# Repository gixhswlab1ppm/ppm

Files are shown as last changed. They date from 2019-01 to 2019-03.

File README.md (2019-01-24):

# Summary
Table tennis can be an expensive sport to learn, with the quality and costs of coaches being hard to determine. Our project aims to make it easier and cheaper to learn table tennis. Our design objective is to create a hardware device that can be connected to a table tennis paddle and be used for various training purposes. Our first objective is to ensure that we can collect useful data. One way in which we will test that is by using unsupervised learning to help users mimic each other, like you might find with a coach and trainee. Our ending objective is to classify different gestures and moves, then to use that data for more complex learning to help users train independently of a coach through real time feedback and post-training analysis through a web interface.
 
# Statement of Problem
Table tennis (commonly referred to as “ping pong”) is an Olympic sport, and a difficult one to learn on a professional level; some countries only have a handful of professional players, and they tend to have played for a long time, taking lessons for 5-15 years (source). Lessons from professional coaches can cost anywhere from $20-100, and there are a wide number of attacking and defensive strokes that players must learn, as well as transitions from each stroke to the other (source). Approximately 19 million Americans play table tennis (source), but only 9000 Americans are registered in the national semi-professional organization (source). This means that almost all table tennis players in the United States have not had professional training.

# Technical Documentation
It's using Python and Arduino/Raspberry Pi. It does ML via sklearn, and data viz via matplotlib.

# Usage Instructions
Run the file

# Notes:
Manually measured swing-period:
cutuy_swing_walk 2s

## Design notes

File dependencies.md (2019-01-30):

# rpi-dep
- pyserial (import serial)
- 
# ard-dep
- MPU6050_tockn (Arduino IDE; source code modified)
- 
# viz-dep
- 

# dev-dep

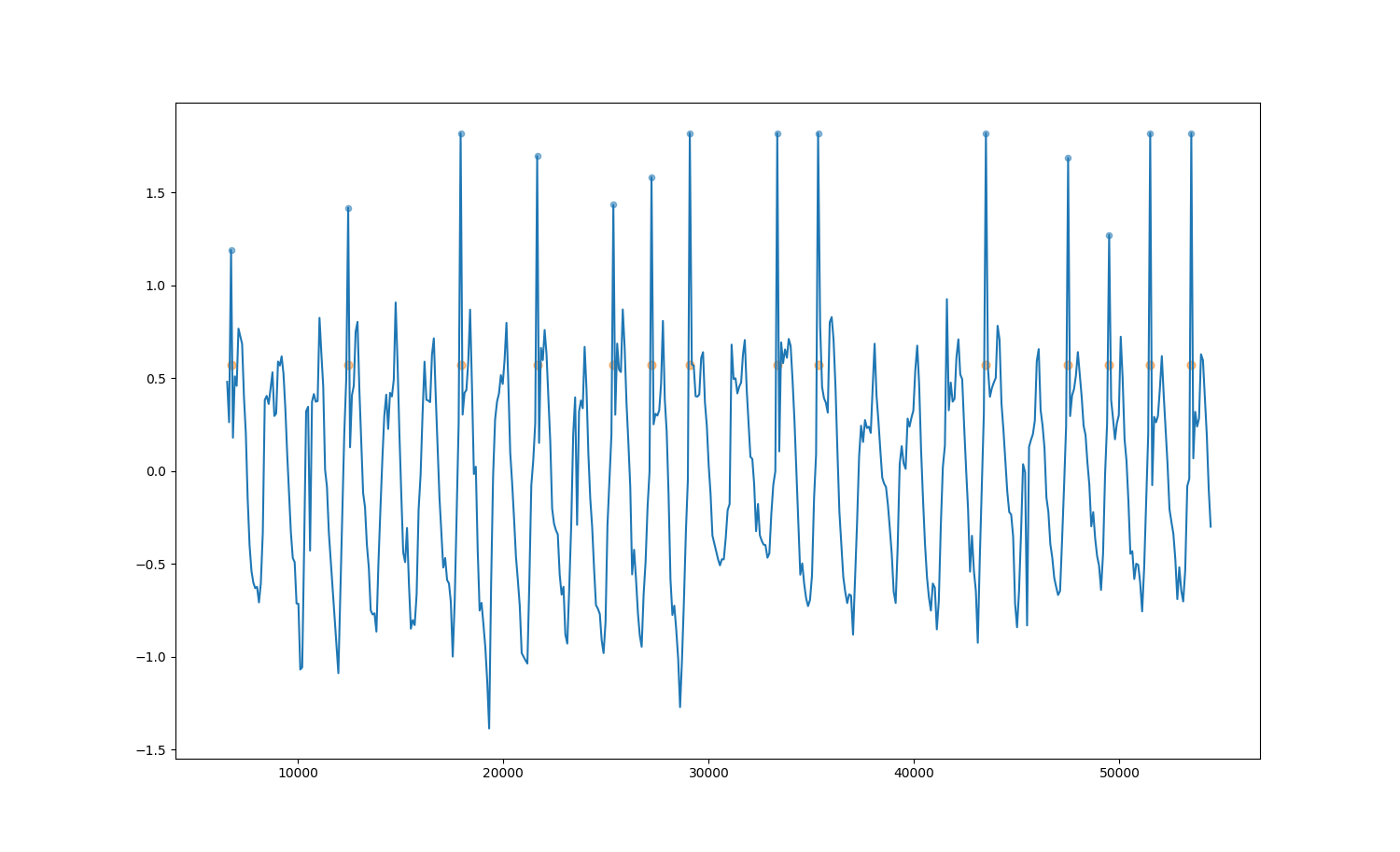
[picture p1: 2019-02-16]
insights/Figure_10.png

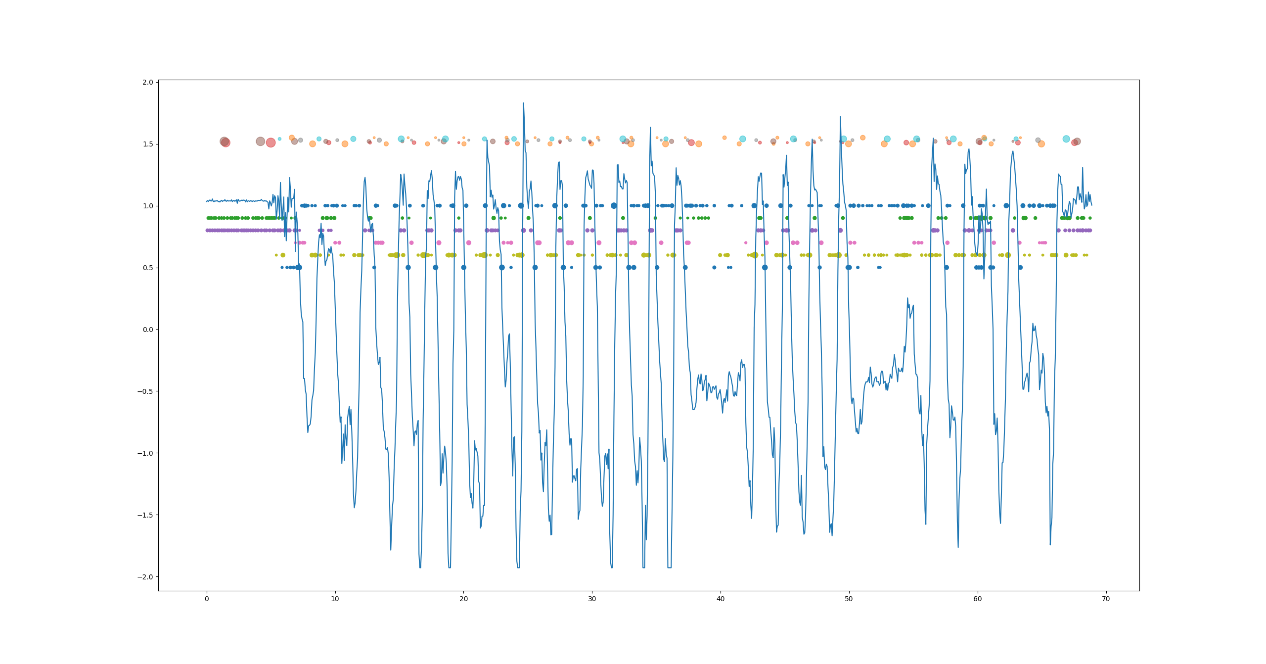
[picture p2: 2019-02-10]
insights/Figure_2.png

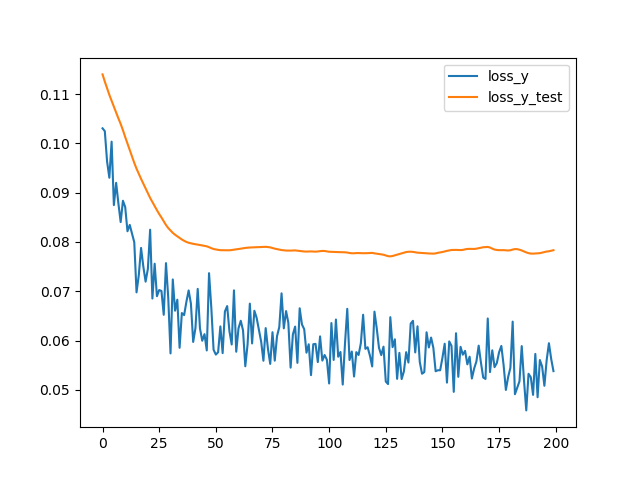
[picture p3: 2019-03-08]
insights/Figure_37.png

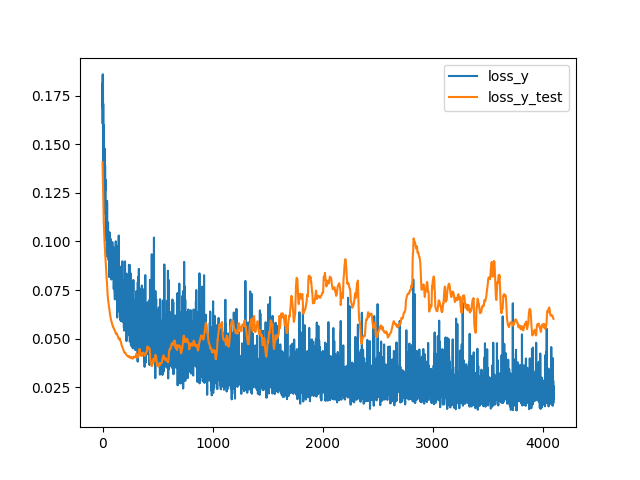
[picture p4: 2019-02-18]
insights/Figure_30.png

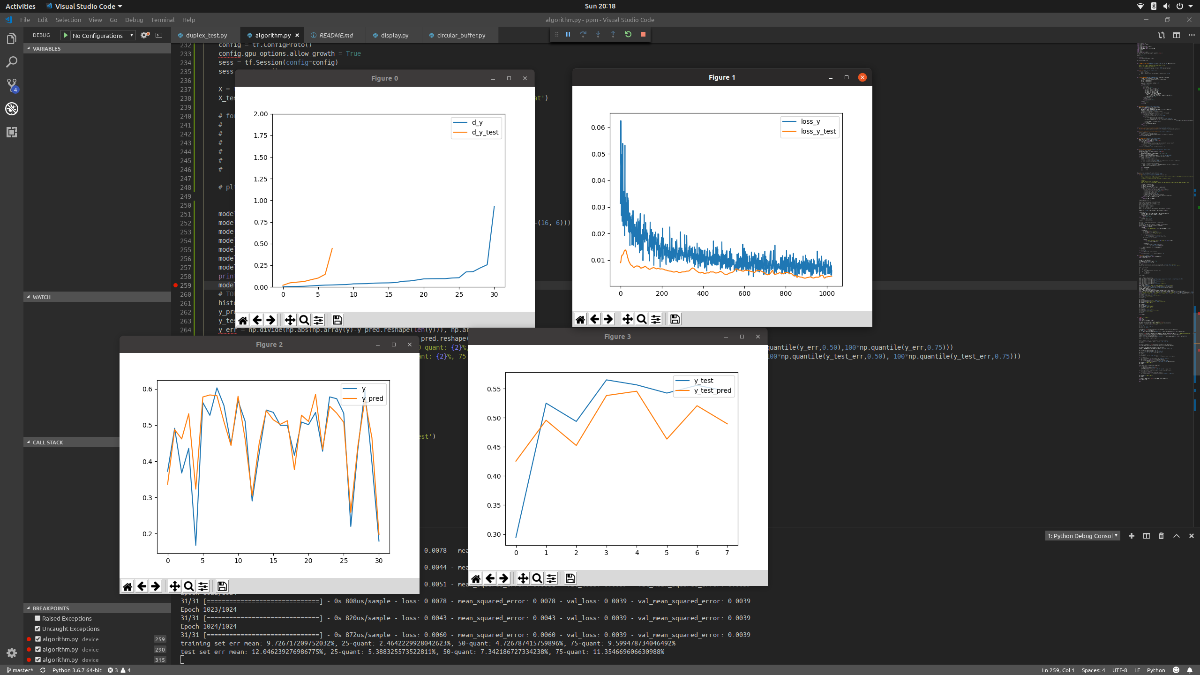
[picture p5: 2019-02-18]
insights/Screenshot from 2019-02-17 20-18-54.png

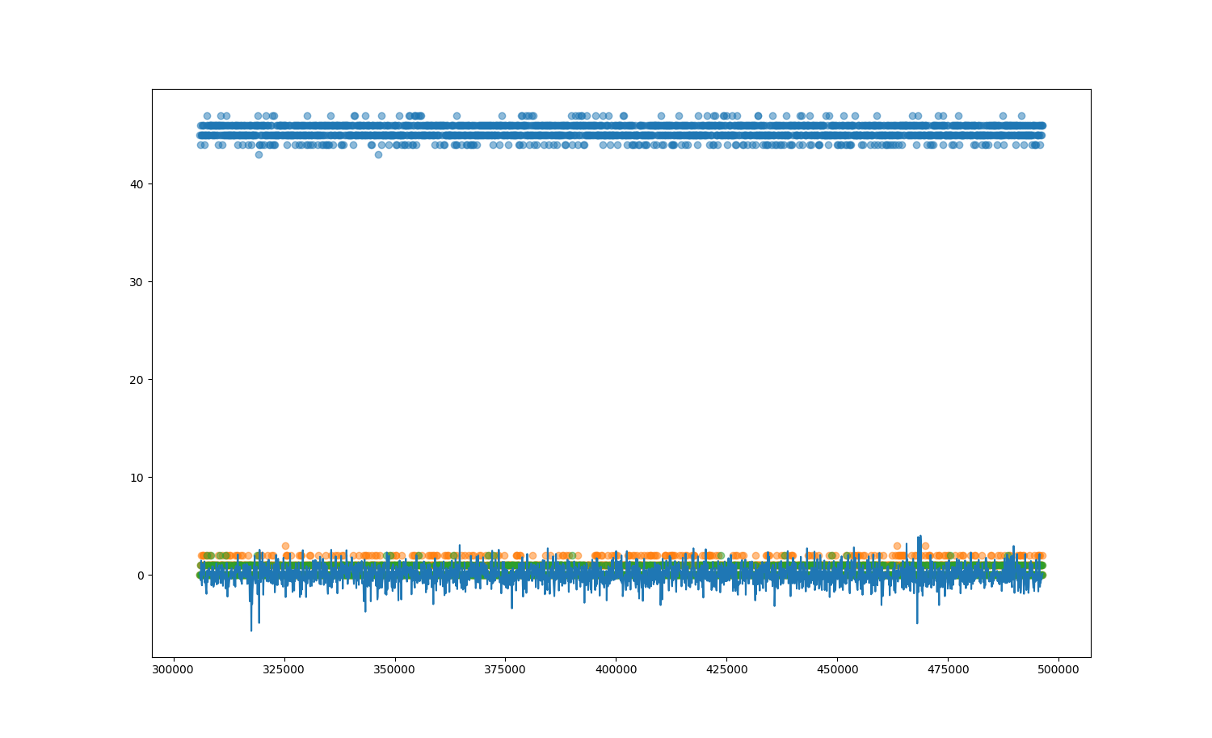
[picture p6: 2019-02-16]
insights/Figure_8.png

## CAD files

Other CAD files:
Paddle RC1.0 (Jason).f3d
Paddle v2 v16.f3d
Paddle v8.f3d

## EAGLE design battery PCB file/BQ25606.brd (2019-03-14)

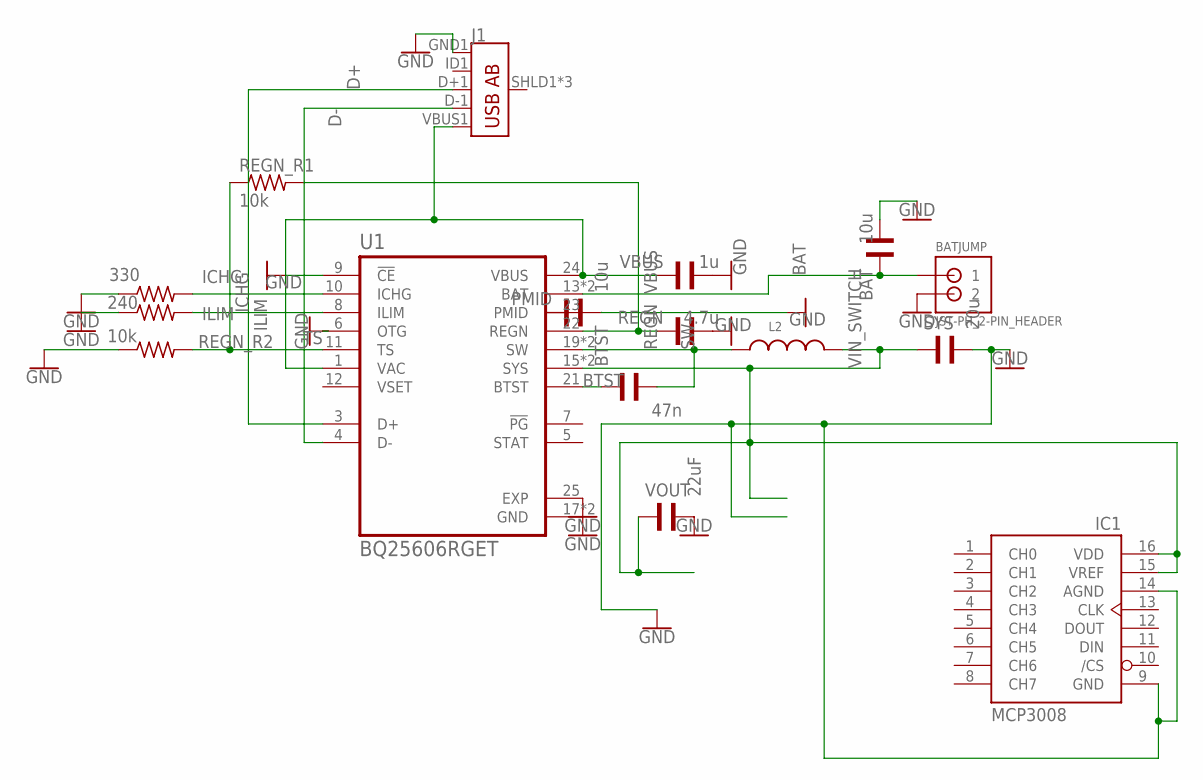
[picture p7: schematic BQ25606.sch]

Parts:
BAT: 10u; WCAP-CSMH_0805_REFLOW; MPN GRM21BR61E106KA73L
BATJUMP: JST-PH_2-PIN_HEADER; JST_B2B-PH_HEADER
BTST: 47n; WCAP-CSGP_0805_WAVE; MPN MC0805B473K500CT
IC1: MCP3008; DIL16
ICHG: 330; M0805; MPN RR1220P-331-D
ILIM: 240; M0805
J1: USB_AB_SMT; USB-AB-MICRO-SMD
L2: WE-PMI_0805_74479775215; WE-PMI_0805
PMID: 10u; WCAP-CSMH_0805_REFLOW; MPN C2012X5R1A226M125AB
REGN: 4.7u; WCAP-CSGP_0805_WAVE; MPN C2012X5R1H475K125AB
REGN_R1, REGN_R2: 10k; M0805; MPN ERJ-6ENF1002V
SYS: 20u; WCAP-CSMH_0805_REFLOW; MPN CC0402KRX5R6BB105
U1: BQ25606RGET; QFN50P400X400X100-25N270X270; MPN BQ25606RGET .
VBUS: 1u; WCAP-CSMH_0805_REFLOW; MPN MCTT21X105K160CT
VOUT: 22uF; WCAP-CSMH_0805_REFLOW; MPN CC0402KRX5R6BB105

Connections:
BAT: BAT.2, BATJUMP.P1 (1), U1.13 (BAT), U1.14 (BAT)
BTST: BTST.2, U1.21 (BTST)
D+: J1.D+1 (D+), U1.3 (D+)
D-: J1.D-1 (D-), U1.4 (D-)
GND: BAT.1, BATJUMP.P2 (2), IC1.9 (GND), IC1.14 (AGND), ICHG.1, ILIM.1, J1.GND1 (GND), PMID.1, REGN.1, REGN_R2.1, SYS.1, U1.6 (OTG), U1.9 (!CE), U1.17 (GND), U1.18 (GND), U1.25 (EXP), VBUS.1, VOUT.1
ICHG: ICHG.2, U1.10 (ICHG)
ILIM: ILIM.2, U1.8 (ILIM)
PMID: U1.23 (PMID)
REGN: REGN.2, REGN_R1.2, U1.22 (REGN)
SW: BTST.1, L2.1, U1.19 (SW), U1.20 (SW)
TS: REGN_R1.1, REGN_R2.2, U1.11 (TS)
VBUS: J1.VBUS1 (VBUS), U1.1 (VAC), U1.24 (VBUS), VBUS.2
VIN_SWITCH: IC1.15 (VREF), IC1.16 (VDD), L2.2, SYS.2, U1.15 (SYS), U1.16 (SYS), VOUT.2

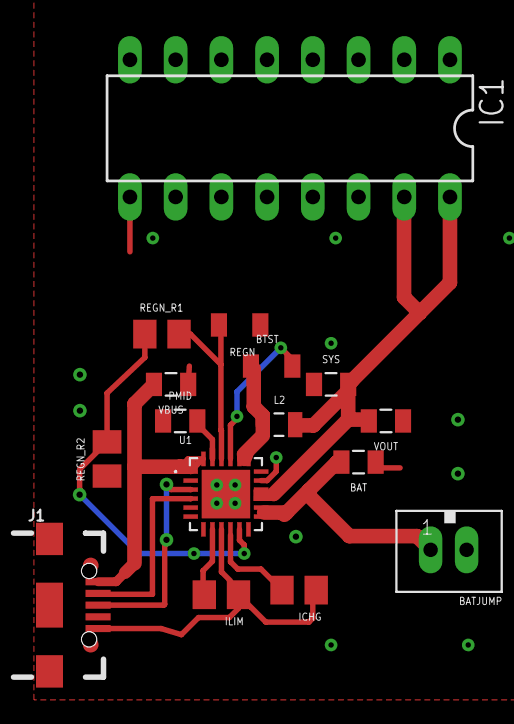
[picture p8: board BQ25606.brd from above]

Board: 2 copper layers, 16 parts (0 on the bottom side), 12 nets.

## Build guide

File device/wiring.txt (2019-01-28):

RPi <-> Arduino Uno <-> 3 x Contact Mic (A0-A2) + 1 x IMU (A4-A5)

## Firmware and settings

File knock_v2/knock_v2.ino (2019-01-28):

/*
  Knock Sensor

  This sketch reads a piezo element to detect a knocking sound.
  It reads an analog pin and compares the result to a set threshold.
  If the result is greater than the threshold, it writes "knock" to the serial
  port, and toggles the LED on pin 13.

  The circuit:
  - positive connection of the piezo attached to analog in 0
  - negative connection of the piezo attached to ground
  - 1 megohm resistor attached from analog in 0 to ground

  created 25 Mar 2007
  by David Cuartielles <http://www.0j0.org>
  modified 30 Aug 2011
  by Tom Igoe

  This example code is in the public domain.

  http://www.arduino.cc/en/Tutorial/Knock
*/


// these constants won't change:
const int ledPin = 13;      // LED connected to digital pin 13
const int knockSensor_1 = A0; // the piezo is connected to analog pin 0
const int knockSensor_2 = A1; // the piezo is connected to analog pin 0
const int knockSensor_3 = A2; // the piezo is connected to analog pin 0
const int threshold = 10;  // threshold value to decide when the detected sound is a knock or not


// these variables will change:
int sensorReading_1 = 0;      // variable to store the value read from the sensor pin
int sensorReading_2 = 0;      // variable to store the value read from the sensor pin
int sensorReading_3 = 0;      // variable to store the value read from the sensor pin
int ledState = LOW;         // variable used to store the last LED status, to toggle the light

void setup() {
  pinMode(ledPin, OUTPUT); // declare the ledPin as as OUTPUT
  Serial.begin(9600);       // use the serial port
}

void loop() {
  // read the sensor and store it in the variable sensorReading:
  sensorReading_1 = analogRead(knockSensor_1);
  if (sensorReading_1 > threshold) {
    Serial.println("sensor 1:");
    Serial.println(sensorReading_1);
  }
  sensorReading_2 = analogRead(knockSensor_2);
  if (sensorReading_2 > threshold) {
    Serial.println("sensor 2:");
    Serial.println(sensorReading_2);
  }
  sensorReading_3 = analogRead(knockSensor_3);
  if (sensorReading_3 > threshold) {
    Serial.println("sensor 3:");
    Serial.println(sensorReading_3);
  }
  // if the sensor reading is greater than the threshold:
  if (sensorReading_1 + sensorReading_2 + sensorReading_3 >= (threshold * 3)) {
    // toggle the status of the ledPin:
    ledState = !ledState;
    // update the LED pin itself:
    digitalWrite(ledPin, ledState);
    // send the string "Knock!" back to the computer, followed by newline
    Serial.println("Knock!");
    Serial.println("Estimate: ");
    if (sensorReading_3 < sensorReading_1) {
      if (sensorReading_3 < sensorReading_2) {
        Serial.println("Ball in between 1 and 2");
      }
    }
    if (sensorReading_2 < sensorReading_1) {
      if (sensorReading_2 < sensorReading_3) {
        Serial.println("Ball in between 1 and 3");
      }
    }
    if (sensorReading_1 < sensorReading_3) {
      if (sensorReading_1 < sensorReading_2) {
        Serial.println("Ball in between 3 and 2");
      }
    }
  }
  delay(100);  // delay to avoid overloading the serial port buffer
}

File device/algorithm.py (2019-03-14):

import numpy as np
import math
from collections import Counter
from scipy import stats
from scipy.signal import argrelextrema
import ujson
import os
from scipy import stats
dir_path = os.path.dirname(os.path.realpath(__file__))

visualize = False
debug = False

hit_th = 200
hit_cluster_size = 1000
ts_col = 0
mpu_cols = [1, 2, 3, 4, 5, 6]
hit_cols = [7, 8, 9]

if visualize == True:
    import matplotlib.pyplot as plt

#  stateless algorithms


# center must be (0,0)
def triangulate_centroid(readings, circles=[[-1/2, -math.sqrt(3)/6], [0, 1./math.sqrt(3)], [1/2, -math.sqrt(3)/6]]):
	"""
	Given a 1x3 array of readings, and 3x2 array of circles
	Returns the weighted centroid (1x2)
	"""
	return np.divide(np.dot(readings, circles), .00001+np.sum(readings))


def shift_mean(data, ts_col, feature_cols):
    return np.hstack([
        data[:, [ts_col]],
        data[:, feature_cols] - np.mean(data[:, feature_cols], axis=0)
    ])


def clustering_dedup(maximas, seg_span=1500):  # maximas: timestamps
        # merge within window until no change
        # 2-level clustering (dedup then detect, respectively)
        idx_min = maximas.min()
        idx_max = maximas.max()

        segs = np.array(maximas).reshape(-1, 1)
        if debug == True:
            print(len(segs))
        while True:
            curr_seg_idx = 0
            epoch_updated = False
            while curr_seg_idx < len(segs) - 1:
                curr_seg = segs[curr_seg_idx]
                next_seg = segs[curr_seg_idx+1]
                curr_mean = np.mean(curr_seg)
                next_mean = np.mean(next_seg)
                if next_mean - curr_mean < seg_span:
                    segs = [*segs[:curr_seg_idx],
                            [*curr_seg, *next_seg], *segs[curr_seg_idx+2:]]
                    epoch_updated = True
                curr_seg_idx += 1
            if debug == True:
                print(len(segs))
            if epoch_updated == False:
                break
        if debug == True:
            print("!!!")
        return segs


def swing_count_svc(data, ts_col, feature_cols, pre_thresholds=None): # =[.3, .2, .34, 50, 30, 35]
    # data = shift_mean(data, ts_col, feature_cols)
    cluster_ts_per_feature = []
    curr_thresholds = np.ndarray((len(feature_cols)))
    for i in range(0, len(feature_cols)):
        maxima_idx = np.array(argrelextrema(data[:, i+1], np.greater))[0]
        curr_thresholds[i] = data[:, i+1].std()*0.6
        if pre_thresholds is None:
            threshold = curr_thresholds[i]
        else:
            threshold = pre_thresholds[i]

        maxima_idx_filtered = [
            m_i for m_i in maxima_idx if data[m_i, i+1] > threshold]
        if len(maxima_idx_filtered) > 0:
            cluster_ts = clustering_dedup(
                data[maxima_idx_filtered, 0], seg_span=1500)
            if visualize:
                plt.scatter(data[maxima_idx_filtered, 0],
                            data[maxima_idx_filtered, i+1], s=20, alpha=.5)
                plt.scatter([np.mean(tsd) for tsd in cluster_ts], pre_thresholds[i] * np.ones(len(cluster_ts)), s=40, alpha=.5)
                plt.plot(data[:, 0], data[:, i+1])
                plt.show()
            cluster_ts_per_feature.append(cluster_ts)
        else:
            cluster_ts_per_feature.append([])
    return cluster_ts_per_feature, curr_thresholds


def get_swing_count_from_ts_clusters_by_feature(ts_clusters_by_feature):
    return int(np.round(np.median([len(clusters) for clusters in ts_clusters_by_feature])))


def get_swing_centers_from_ts_cluster_by_feature(ts_clusters_by_feature):
    centers_by_feature = []
    for clusters in ts_clusters_by_feature:
        centers_by_feature.append([np.mean(cluster) for cluster in clusters])
    return centers_by_feature


def get_hit_dispersity_temporal(hit_event):
    reading_sum = np.sum(hit_event[:, 1:])
    t_center = np.sum(np.dot(hit_event[:, 0], hit_event[:, 1:]))/reading_sum
    dist_sum = np.sum(
        np.dot(np.abs(hit_event[:, 0]-t_center), hit_event[:, 1:]))
    return dist_sum/reading_sum


def get_hit_dispersity_spatial(hit_event):
    s_center = np.mean([triangulate_centroid(row)
                        for row in hit_event], axis=0)
    # if debug & visualize:
    #     centers = np.array([triangulate_centroid(row)
    #                     for row in hit_event])
    #     plt.scatter(centers[:, 0], centers[:, 1], alpha=.5)
    #     plt.plot([-1/2, 1/2, 0, -1/2], [-math.sqrt(3)/6, -math.sqrt(3)/6, math.sqrt(3)/3, -math.sqrt(3)/6])
    #     plt.show()
    return np.linalg.norm(s_center)


def hit_report_svc(data, ts_col, hit_cols):
    valued_indices_mask = np.zeros(len(data), dtype=bool)
    for hc in hit_cols:
        valued_indices_mask[np.argwhere(data[:, hc] > hit_th)] = True
    if np.sum(valued_indices_mask) > 0:
        hit_events = clustering_dedup(
            data[np.argwhere(valued_indices_mask == True), 0], seg_span=hit_cluster_size)
        n_event = len(hit_events)
        # features per "hit event"

        hit_dispersity_temporal = np.empty(
            n_event, dtype=float)  # bound by hit event length
        # hit_dispersity_spatial = np.empty(
        #     n_event, dtype=float)  # bound by hit triangle size
        hit_strength = np.empty(n_event, dtype=float)  # bound by hit reading

        for i, event_ts in enumerate(hit_events):
            indices = np.intersect1d(np.argwhere(
                data[:, ts_col] >= event_ts[0]), np.argwhere(data[:, ts_col] <= event_ts[-1]))
            hit_event_with_ts = data[:, [ts_col, *hit_cols]][indices]

            hit_dispersity_temporal[i] = np.min(
                (1., get_hit_dispersity_temporal(hit_event_with_ts)/(1 << 7)))
            # hit_dispersity_spatial[i] = get_hit_dispersity_spatial(
            #     hit_event_with_ts[:, 1:])
            # sum of max reading along each ts
            hit_strength[i] = np.min(
                (1., np.sum(np.max(hit_event_with_ts[:, 1:], axis=0))/(1 << 9)))
        return hit_dispersity_temporal, hit_strength, hit_events
    else:
        return [], [], []
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

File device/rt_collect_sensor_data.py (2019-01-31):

# Sensor data collection on Raspberry Pi in real-time
sample_rate = 0.005  # 5e-3s, 5ms
# WARNING must keep sampling consistency!

import pandas as pd
import numpy as np
import matplotlib.pyplot as plt
from scipy import signal
import math
from sklearn.decomposition import PCA
from sklearn.preprocessing import StandardScaler
from collections import Counter
import ujson
from scipy import stats
from scipy.signal import argrelextrema

swing_period = (1.5, 3)

def fft(y_temp, topk=.1):
    """
    Given a feature vector (1-D) sorted in time domain, this function performs a Fast DFT (real part only) and returns:
    x_freq: frequencies in frequency domain
    y_freq_abs | y_freq_abs_filtered: amplitude in frequency domain 

    Arguments:
    y_temp: feature vector in time domain
    topk: \in (0,1) | [1, len(y_temp)]; returns the top frequencies & amplitudes by top percentage or count
    """
    y_temp -= np.mean(y_temp)
    y_freq = np.fft.rfft(y_temp)
    y_freq_abs = np.abs(y_freq)
    x_freq = np.fft.rfftfreq(len(y_temp), d=sample_rate)
    if topk != None:
        topk = int(topk*len(y_freq)) if topk<1 else topk
        y_freq_idx_by_amp = np.argsort(y_freq_abs)[::-1][:topk]
        y_freq_mask = np.ones(len(y_freq), dtype=bool)
        y_freq_mask[y_freq_idx_by_amp] = False
        y_freq_filtered = y_freq.copy()
        y_freq_filtered[y_freq_mask] = 0
        y_freq_abs_filtered = np.abs(y_freq_filtered)
        # return x_freq, y_freq_abs_filtered/y_freq_abs_filtered.max()
        return x_freq, y_freq_abs_filtered
    else: 
        return x_freq, y_freq_abs

mpu = ujson.load(open('C:\\Users\\James\\ppm2\\device\\1548719339.7204287.json','r'))
mpu = np.array(mpu)
mpu_time_col = mpu[:, -1].copy()
mpu[:, -1] = mpu[:, 0].copy()
mpu[:, 0] = mpu_time_col.copy()
mpu_time_min = mpu[:,0].min()
mpu_time_max = mpu[:,0].max()
mpu[:, 0] -= mpu_time_min
mpu[:, 0] = np.linspace(0, mpu_time_max - mpu_time_min, len(mpu))

sample_rate = (mpu_time_max - mpu_time_min)/len(mpu)
# mpu[:,0] -= mpu[0,0]
# tf = np.arange(0, np.max(mpu[:, 0]), sample_rate)
# mpu = mpu[[np.argmin(abs(mpu[:, 0]-t)) for t in tf]]
# mpu[:, 0] = np.array(tf)

data = mpu[:, [0,2,3,4,5,6,7]]
n_feature = 6

## if VIZ
for i in range(0, n_feature):
    x, y = fft(data[:, i+1])
    print("All Data")
    ind_y = np.argsort(y)[::-1]
    print("Main periods: ", 1/x[ind_y[0]], 1/x[ind_y[1]], 1 /
          x[ind_y[2]], 1/x[ind_y[3]], 1/x[ind_y[4]], 1/x[ind_y[5]])
    # plt.scatter(x, y, label=i, alpha=.5, s=100*y)
    plt.scatter(x, y, label=i, alpha=.5)
plt.legend(loc='upper left')
plt.show()
## endif

period_poll = []
t_window = 10
n_window = math.floor(data[-1, 0]/t_window)
n_winlen = math.floor(data.shape[0]/n_window)
fft_freqs = np.fft.rfftfreq(n_winlen, d=sample_rate)
fft_topk = 20
fft_amps = np.ndarray((n_feature, n_window, len(fft_freqs))) # 2D (feature, window) array of (list of) amps
maxima_store = []

for i in range(0, n_feature):
    print(i, " th feature stats", stats.describe(data[:, i+1]))
    
    maxima_idx = np.array(argrelextrema(data[:, i+1], np.greater))[0]
    threshold  = data[:, i+1].std()/2
    maxima_idx_filtered = [m_i for m_i in maxima_idx if data[m_i, i+1] > threshold]
    maxima_store.append(maxima_idx_filtered)
    print('detected ', len(maxima_idx_filtered), ' peaks')
    # TODO use detected main freqs to reduce duplicates
    plt.xlim(0, 10)  # max freq should be at the 2nd column
    plt.legend(loc='upper right')
    plt.figure(str(i) + '-th data')
    plt.plot(data[:, 0], data[:, i+1])
    plt.scatter(data[maxima_idx_filtered,0], data[maxima_idx_filtered,i+1])

    print('Feature {0}'.format(i))
    plt.figure(str(i) + '-th spectrum')
    for j in range(0, n_window):
        x, y = fft(data[n_winlen*j:n_winlen*(j+1), i+1], topk=fft_topk)
        fft_amps[i,j,:] = y.copy()
        # plt.scatter(x+j*20, y, label=n_winlen*j+i, alpha=.5)
        plt.scatter(1/x, y, label=n_winlen*j+i, alpha=.5, s=100*y/max(y))
        print('Main freq:', x[np.argmax(y)], np.argmax(y))

        main_signal_idx = np.argmax(y)
        main_signal_period = 1/x[main_signal_idx]
        main_signal_amp = y[main_signal_idx]

        if main_signal_period >= swing_period[0] and main_signal_period <= swing_period[1]:
            period_poll.append((main_signal_period, main_signal_amp))

            # print('Main period:', 1/x[np.argmax(y)])
        # plt.legend(loc='upper left')
    # overall fft
    

# TODO: handle empty array case
period_pred = np.max([val for val, count in Counter([p for p,a in period_poll]).most_common(1)])
print('Predicted main period', period_pred)
print(period_poll)

# Use period_pred to dedup maxima_store
for p_idx_list in maxima_store:
    pass
# TODO: {outlier detection | swing detection} by levels: window, timestamp?





plt.show()
## endif


# WARNING Scaler is in question...
# scaler = StandardScaler()
# data = scaler.fit_transform(data[:,1:])
# pca = PCA().fit(data[:,1:])
# print(pca.explained_variance_ratio_)


pass
# df1 = pd.read_csv('gyroscope.csv', header=0)
# y1 = df1[acc_feature].values
# fft(y1)

# y2 = y1[2000:6000]
# fft(y2)

# #df.plot()
# #plt.show()


# TODO: CANCELLED adjacent frequencies combination
# This is not mathematically correct.

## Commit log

2019-01-19 Impl FFT test
    [accelerometer.csv]
2019-01-19 Add new datasets; impl viz for spectrum comparison
    [accelerometer_2.csv, accelerometer_3.csv, accelerometer_4.csv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]
2019-01-24 Cirtical bug fix for timestamp alignment for raw data; impl period estimation; verify algorithm on swing+walk datasets; gather new datasets; add docs for fft function
    [accelerometer_2.csv, accelerometer_3.csv, accelerometer_4.csv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]
2019-01-26 Collect data from mpu wired to RPi; add code path for mpu data for fft analysis
2019-01-26 arduino code for penziometer triangulation
2019-01-28 Test duplex over serial over USB between Arduino & Pi; impl data reporting from Arduino to Pi
2019-01-28 Style fixing & restructuring
    [GetAllData.ino, rt_collect_sensor_data.py]
2019-01-29 Add IMU + Piezo collected data; impl Pi code that emits file w/ respect to a switch on Arduino; impl simple swing counter
2019-01-31 Fix bug after Nano migration; move swing detection code to Pi
    [GetAllData.ino, duplex_test.py, rt_collect_sensor_data.py]
2019-01-31 Add sensor data; integrate triangulation into RT pipeline
2019-02-07 Milestone 1 demo day hotfix - skipping topk count
    [rt_collect_sensor_data.py]
2019-02-10 Add per-feature-level dedup logic for peak detection; add ts col in data packet; data normalization for IMU cols now *before* fft.
2019-02-10 Update arduino code for new packet format; wrap swing_count, hit_detection as services; impl real-time pipeline
2019-02-11 Impl logic for hw button for activity start/end
2019-02-12 Minor bug fixes for algorithm & GetAllData output; improve debug experience
    [GetAllData.ino, algorithm.py, circular_buffer.py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]
2019-02-14 Minor bug fixes & add tests for algorithm svcs
    [algorithm.py]
2019-02-14 e-ink code in arduino and rpi folders
2019-02-15 Add lib for e-ink display manipulation; fix bug during dumping in circular_buffer; add sensor data for new dt.
    [circular_buffer.py, display.py, epd2in13d.py]
2019-02-15 Remove redundant sample files for e-ink display
2019-02-15 Minor bug fixes & add viz for algorithm; update req docs
    [algorithm.py]
2019-02-16 Improve folder structure readilibilty
    [accelerometer_cutuy_swing.csv, accelerometer_cutuy_swing_walk.csv, accelerometer_josh_swing_walk.csv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]
2019-02-16 Add new data after fixing piezo hardware; add viz code for ball-hit & swing-count correlation; add viz insights
    [algorithm.py]
2019-02-20 enclosure paddle V2
    [Paddle v8.f3d]
2019-02-20 Add paddle design (Jason)
    [Paddle RC1.0 (Jason).f3d]
2019-02-25 Add remote path to file emission; add sensor data
2019-03-07 Add sensor data;
2019-03-09 Add sensor data & resources; improve algorithm code readibility
2019-03-09 Minor bug fixes & test for swing count based on threshold learning result
    [algorithm.py, duplex_test.py, profile_manager.py]
2019-03-10 added file switching, raw data switching
2019-03-10 Improve threading parallelism and real-time responsiveness
2019-03-14 eagle pcb file and fusion 3d cad file
    [BQ25606.brd, BQ25606.sch, Paddle v2 v16.f3d]
2019-03-14 Hotfix code for M3 prototype

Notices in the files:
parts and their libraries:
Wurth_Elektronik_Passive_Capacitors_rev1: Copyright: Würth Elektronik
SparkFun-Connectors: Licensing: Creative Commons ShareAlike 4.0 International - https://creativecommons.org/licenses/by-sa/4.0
